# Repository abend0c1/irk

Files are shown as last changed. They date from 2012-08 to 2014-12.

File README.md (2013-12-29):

IRK! Infrared Remote USB Keyboard
=================================
Control your computer with an IR remote
---------------------------------------

IRK! is an open-hardware Infrared Remote Controlled USB keyboard, without keys, implemented using a PIC micro-controller and MikroC. It enables you to use your *learning* remote control to control any system that you can plug a USB keyboard into (Windows, Linux, Mac). Great for controlling a home theatre system such as MythTV, XBMC or Media Center. No drivers are required.

Note: Your IR remote *must* be able to *learn* infrared control signals. You *cannot* use a pre-programmed remote control with IRK!.

The original intention was to allow a user to control MythTV home theatre software using an infrared remote control. As it is seen by a PC as just another USB keyboard it can be used to control other PC functions as well.

What makes this unit different from the rest is that it can *teach* a learning remote control the IR code associated with a particular USB keystroke. As a result, there are *no* pre-programmed IR codes and IRK! does *not* have to support all the different types of infrared remotes on the market - it *teaches* the remote IRK!'s own infrared commands - which can be anything! Currently, IRK! uses Pulse Width Modulation (PWM) to encode/decode the infrared signals.

You can program -any- USB keyboard function (with or without Control, Alt, Shift and GUI modifiers) to a button on your infrared remote control and when you press that button IRK! will send the corresponding USB keystroke to the host computer.

You can program -any- USB Consumer Device control code too - for example, Play, Pause, Mute, Volume up, Volume down, and many others.

Features
--------
- Teaches your LEARNING remote control IR codes
- Lets you map IR codes to USB keystrokes - for example, Shift+Enter
- Sends the USB keystroke to your PC when you press a button on your infrared remote control
- Can send USB System Control codes (Power off, sleep, wake) to your PC
- Can can have one of 256 addresses - so you can have multiple IRK!'s
- Handles broadcasts - so multiple IRK!'s can respond to a single IR button
- Can remotely press the POWER and RESET buttons on your PC (if wired)
- Supports USB Consumer Device functions (e.g. Mute, Play, Pause, Stop, etc.)
- Has a programmable LCD backlight delay (and backlight ON/OFF commands)
- Requires NO drivers for Windows/Linux etc
- The Printed Circuit Board (PCB) comes in two flavours: 
  - Surface Mount Technology (SMT) and 
  - Through Hole Technology (THT)

Construction
------------
Go to the [Instructables](http://www.instructables.com/id/IRK-Infrared-Remote-Controlled-USB-Keyboard/) web site for detailed information on how to build your own unit.

Front Panel Buttons
-------------------

The front panel buttons comprise:

- UP - Press to increment the displayed function code. Press and hold to repeatedly increment the function code.
- DOWN - Press to decrement the displayed function code. Press and hold to repeatedly decrement the function code.
- OK - Press to accept an entry, or to cause the selected function to be executed.
- TEACH - Press to transmit a code representing the currently selected function to your IR remote control so that it can "learn" it.
- CTL - Press to toggle the keyboard "Ctrl" key. Press *and hold* to toggle the keyboard "GUI" key. The "GUI" key is a generic name for the "Windows" key on Microsoft keyboards, the "Apple" key on Apple keyboard, or the "Meta" or "Super" key on other keyboards. 
- ALT - Press to toggle the keyboard "Alt" key 
- SHIFT - Press to toggle the keyboard "Shift" key. Press *and hold* to select a different "usage page" (currently you can choose from Keyboard, Consumer Device, System Control, and local IRK! functions); then press UP/DOWN and OK to select the "usage page".

Front Panel Display 
-------------------

### Front Panel Display
The user is presented with an LCD 2 x 16 display that looks like:

<table style="border-collapse: collapse; width: 300px; text-align: left; background-color: #ccff00;">
  <tbody style="font-family: Courier New, courier, monospace; font-size: 20px; font-weight: bold; border: 10px solid #000000;">
    <tr><td style="padding-left:10px;width: 40px;">ux</td><td>line1</td></tr>
    <tr><td style="padding-left:10px;width: 40px;">yy</td><td>line2</td></tr>
  </tbody>
</table>

The codes, ux and yy, are hexadecimal values (that is, each digit can be from 0 to 9 and A to F).

-  u = The USB Usage Page index (i.e. used to assign meaning to the
      following x and yy codes). Press and hold the SHIFT button and
      then press the UP/DOWN buttons to cycle through the usage page
      indexes (0 to F and back to 0). At the moment, IRK! uses only
      the following usage page indexes:
    - 0 = Keyboard (A, B, C etc)
    - 1 = System Control (Power off, Sleep, Wake etc)
    - 2 = Consumer Devices (Mute, Vol+, Vol-, Play/Pause etc)
    - F = IRK! Local Functions (LCD backlight on/off etc)
- x = Either:
    - The key modifiers [Ctl, Alt, Shift, GUI] for Keyboard usage (see below), or else
    - The first nybble of xyy (the function to be performed) for all
          other usage pages.
- line1 = Text that describes the ux code
- yy = See below. Press and/or hold the UP and DOWN buttons to change
           the value of xyy.
- line2 = Text that describes the yy (or xyy) code.

The meanings id u, x and yy are as follows:

- When u = 0, xyy represents a Keyboard function:
    - 0x yy
         -    0 = Keyboard device
         -    x = Keyboard modifier (CTRL/ALT/SHIFT/GUI) flag bits (see below)
         -    yy = USB keyboard function code
    - 00 yy   Key yy pressed with no keyboard modifier keys
    - 01 yy   CTRL key pressed along with key yy
    - 02 yy   SHIFT key presed along with key yy
    - 04 yy   ALT key pressed along with key yy
    - 08 yy   GUI key pressed along with key yy
    
    Examples:
    - 00 05   b key pressed (05 is the code for "b")
    - 02 05   SHIFT+b key pressed (i.e. upper case B)
    - 06 05   ALT+SHIFT+b key pressed: 04(ALT) + 02(SHIFT) = 06(ALT+SHIFT)
    - 0C 05   GUI+SHIFT+b key pressed: 04(ALT) + 08(GUI)   = 0C(ALT+GUI)  

- When u = 1, xyy represents a System Control function:
    - 1x yy
         -    1 = System Control
         -    xyy = USB System Control function
    
    Examples:
    - 10 81   Power off
    - 10 82   Sleep
    - 10 83   Wake

- When u = 2, xyy represents a Consumer Device function:
    - 2x yy
         -   2 = Consumer Device
         -   xyy = USB Consumer Device function
     
    Examples:
    - 20 E2   Mute
    - 20 E9   Vol+
    - 20 EA   Vol-
    - 21 95   Internet Browser

- When u = F, xyy represents a local IRK! function (i.e. not USB):
    - Fx yy
         -   F = IRK! device
         -   xyy = Local IRK! device function
    - F0 00   Set Address ... the next LCD display will be:
        -    aa <-- Address
        -    00 Set Address
        -    You then press up/down to cycle the address (aa) then
             press OK to select it. The default address is AA.
    - F0 01   Power Switch
        - The two header pins marked PWR will become low impedance for about
          250 ms.  Note: this is not meant to switch large currents. The 4066
          quad analog switch can pass an absolute maximum of only +/- 25 mA.
    - F0 02   Reset Switch
        - The two header pins marked RST will become low impedance for about
          250 ms.
    - F0 03   Init USB
        - Causes the unit to re-register itself as a USB device. It is
          almost the equivalent of unplugging and replugging the device
          into a USB port.
    - F0 04   Back light off
        - Turns the LCD back light off
    - F0 05   Back light on
        - Turns the LCD back light off
    - F0 06   Set light delay  
        - Lets you set how many seconds you would like the LCD
          backlight to remain on after you have pressed a panel 
          button or issued a valid infrared command.
        - The next LCD display will be one of the following:
            -   xx <-- nnn secs (where nnn is xx in decimal)
            -   FF <-- ON       (keep back light always on)
            -   00 <-- OFF      (keep back light always off)
        -   You then press up/down to choose the delay value (xx) then
            press OK to select it.
    - F0 07   Debug on 
        - Displays debug information on the LCD when an IR code is received
    - F0 08   Debug off 
        - Returns the unit to Normal mode (displays no debug information on the LCD)
    - F0 09   Auxiliary Switch
        - The two header pins marked AUX will become low impedance for about
          250 ms.
    - F0 0A   Power Switch On
        - The two header pins marked PWR will become low impedance until a
          subsequent Power Switch Off command is received.
    - F0 0B   Reset Switch On
        - The two header pins marked RST will become low impedance until a
          subsequent Power Switch Off command is received.
    - F0 0C   Auxiliary Switch On
        - The two header pins marked AUX will become low impedance until a
          subsequent Power Switch Off command is received.
    - F0 0D   Power Switch Off
        - The two header pins marked PWR will become high impedance.
    - F0 0E   Reset Switch Off
        - The two header pins marked RST will become high impedance.
    - F0 0F   Auxiliary Switch Off
        - The two header pins marked AUX will become high impedance.

- Other values (u = 3 to F) are currently reserved for future use.
            
Examples
--------            
1. The user wants to program the Enter key on the OK button of a
   learning remote control. The steps to follow are:
    - Plug IRK! into a host USB port
    - The default usage mode is Keyboard, which is displayed as
    "00 Keyboard" in the first line of the LCD, so just
    press and hold the UP button until the second line of the LCD
    shows "28 Enter".
    - Switch your learning remote control into "Learn" mode and
    select the remote's button to be programmed.
    - Press IRK!'s TEACH button. This will send an IR code that
    means "Enter" to your learning remote.
    - Repeat until the learning remote has learned that IR code.
    - Press the programmed button on the learning remote control.
    - Verify that IRK! has received the IR code (it will flash
    its LED when it has recognised a valid IR code). Verify 
    that the "Enter" USB Keyboard function has been performed
    at the host.

2. The user wants to program the "Mute" Consumer Devices function
   on the "Mute" button of a learning remote control. The default
   usage mode of IRK! is "Keyboard", so you need to switch IRK! into
   "Consumer Dev" mode first:
    - Press and hold IRK!'s SHIFT button until the second line of
    the LCD shows "^^ Select Usage".
    - Press IRK!'s UP button until "20 Consumer Dev" is displayed in
    the first line of the LCD.
    - Press IRK!'s OK button to enter "Consumer Dev" usage mode.
    - Press and hold IRK!'s UP button until "E2 Mute" is displayed
    on the second line of the LCD. If you overshoot then press the
    DOWN button repeatedly until you reach "E2 Mute".
    - Press OK to verify that the Mute function is accepted by the
    host.
    - Put your learning remote control into "Learn" mode and choose
    one of the remote's buttons to be programmed as "Mute".
    - Position your learning remote's IR receiver to within 5 cm of
    IRK!'s IR transmitter LED.
    - Press IRK!'s TEACH button. This will send an IR code that 
    means "Mute" to your learning remote.
    - Keep pressing TEACH until the learning remote has learned that
    IR code.
    - Press the programmed button on the learning remote control.
    - Verify that IRK! has received the IR code (it will flash
    its LED when it has recognised a valid IR code). Verify 
    that the "Mute" USB consumer device function has been performed
    at the host.

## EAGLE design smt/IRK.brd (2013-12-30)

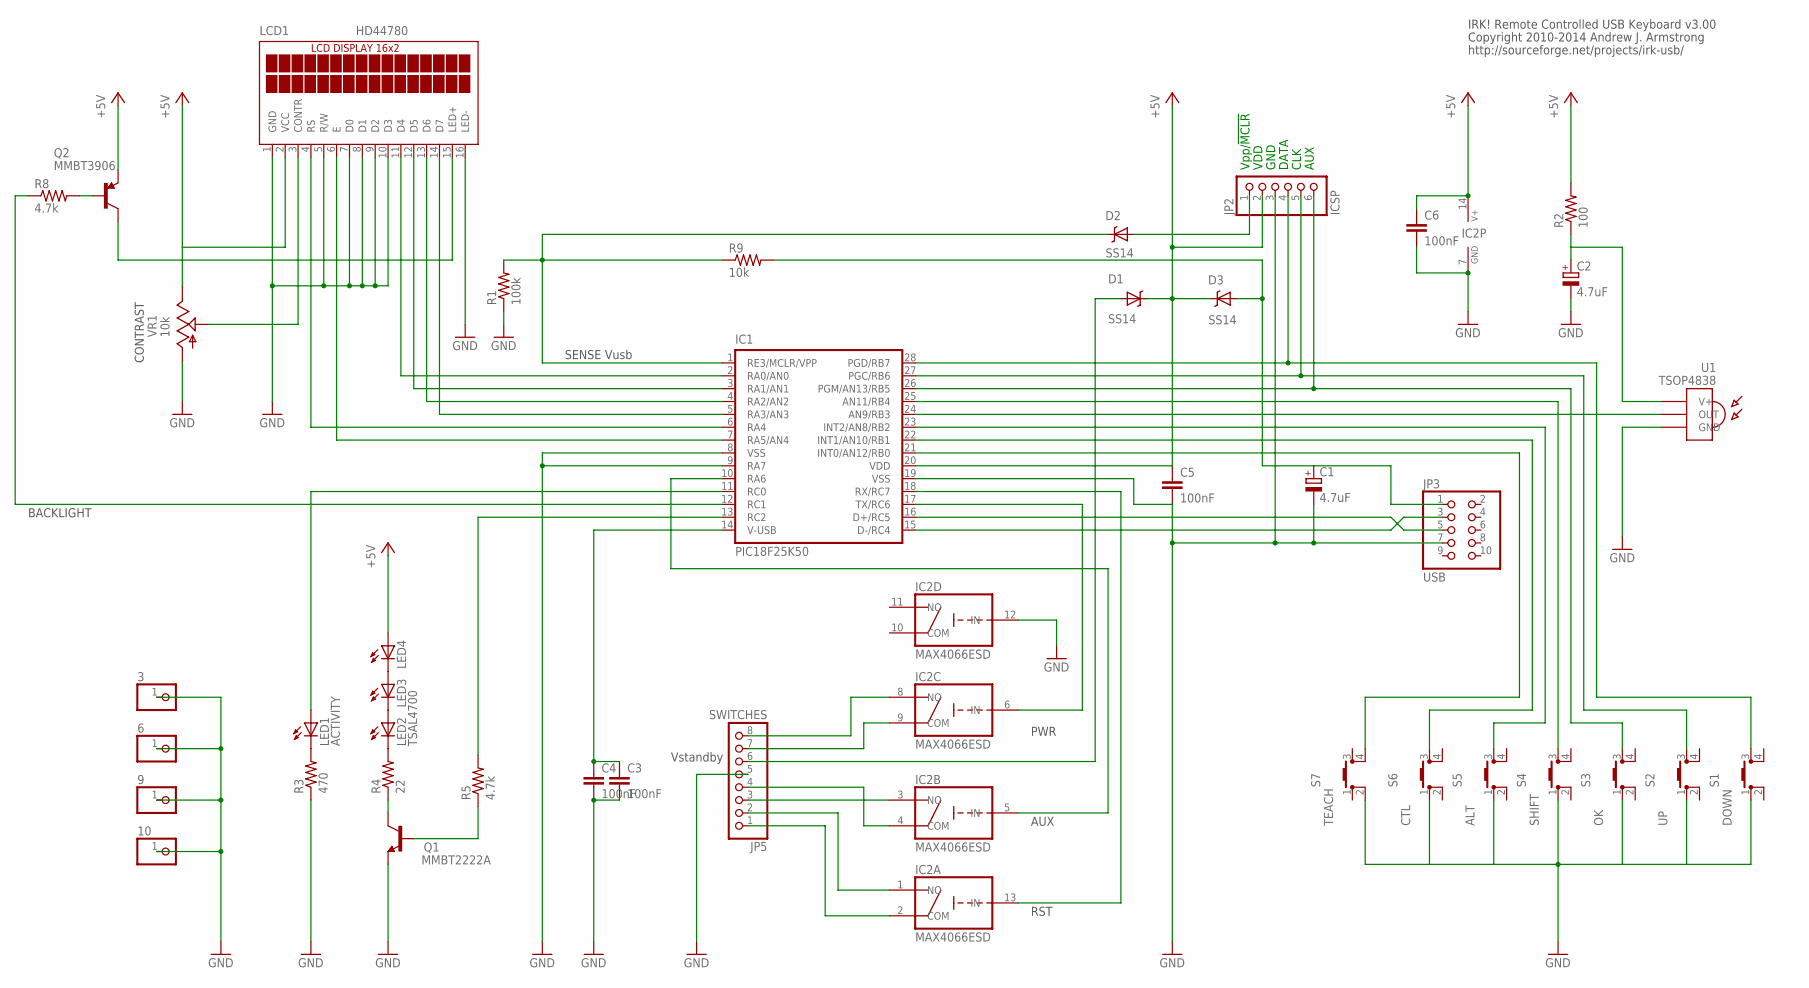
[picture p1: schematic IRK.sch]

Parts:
3, 6, 9, 10: 1X01
C1, C2: 4.7uF; SMC_A
C3, C4, C5, C6: 100nF; C0805
D1, D2, D3: SS14; SMA-DIODE
IC1: PIC18F25K50; SO28W
IC2: MAX4066ESD; SO14
JP2: ICSP; 1X06
JP3: USB; 2X05
JP5: SWITCHES; 1X08
LCD1: HD44780; LCD_16X2
LED1: ACTIVITY; LED5MM
LED2: TSAL4700; LED5MM
LED3, LED4: LED5MM
Q1: MMBT2222A; SOT23
Q2: MMBT3906; SOT23
R1: 100k; M1206
R2: 100; M1206
R3: 470; M1206
R4: 22; M1206
R5, R8: 4.7k; M1206
R9: 10k; M1206
S1: DOWN; PTH525-SM10
S2: UP; PTH525-SM10
S3: OK; PTH525-SM10
S4: SHIFT; PTH525-SM10
S5: ALT; PTH525-SM10
S6: CTL; PTH525-SM10
S7: TEACH; PTH525-SM10
U1: TSOP4838; TSOP18XX
VR1: 10k; 3303W

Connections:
+5V: C5.1, C6.1, D1.K, D3.K, IC1.20 (VDD), IC2.14 (V+), JP2.2, LCD1.2 (VCC), LED4.A, Q2.2 (E), R2.2, VR1.3 (E)
AUX: IC1.10 (RA6), IC2.5 (IN)
GND: 3.1, 6.1, 9.1, 10.1, C1.-, C2.-, C3.2, C4.2, C5.2, C6.2, IC1.8 (VSS), IC1.9 (RA7), IC1.19 (VSS), IC2.7 (GND), IC2.12 (IN), JP2.3, JP3.7, JP5.5, LCD1.1 (GND), LCD1.5 (R/W), LCD1.7 (D0), LCD1.8 (D1), LCD1.9 (D2), LCD1.10 (D3), LCD1.16 (LED-), Q1.2 (E), R1.1, R3.1, S1.1, S2.1, S3.1, S4.1, S5.1, S6.1, S7.2, U1.GND, VR1.1 (A)
unnamed: IC1.2 (RA0/AN0), LCD1.11 (D4)
unnamed: IC1.3 (RA1/AN1), LCD1.12 (D5)
unnamed: IC1.4 (RA2/AN2), LCD1.13 (D6)
unnamed: IC1.5 (RA3/AN3), LCD1.14 (D7)
unnamed: IC1.6 (RA4), LCD1.4 (RS)
unnamed: IC1.7 (RA5/AN4), LCD1.6 (E)
unnamed: LCD1.3 (CONTR), VR1.2 (S)
unnamed: D2.K, IC1.1 (RE3/MCLR/VPP), R1.2, R9.1
unnamed: IC1.24 (AN9/RB3), U1.OUT
unnamed: IC2.2 (COM), JP5.1
unnamed: IC1.28 (PGD/RB7), JP2.4, S1.3
unnamed: IC1.27 (PGC/RB6), JP2.5, S2.3
unnamed: IC1.26 (PGM/AN13/RB5), JP2.6, S3.3
unnamed: IC1.25 (AN11/RB4), S4.3
unnamed: IC1.23 (INT2/AN8/RB2), S5.3
unnamed: IC1.22 (INT1/AN10/RB1), S6.3
unnamed: IC1.21 (INT0/AN12/RB0), S7.4
unnamed: C3.1, C4.1, IC1.14 (V-USB)
unnamed: LED1.K (C), R3.2
unnamed: C1.+, D3.A, JP3.1, R9.2
unnamed: IC2.1 (NO), JP5.2
unnamed: IC1.16 (D+/RC5), JP3.5
unnamed: IC1.15 (D-/RC4), JP3.3
unnamed: LED2.K (C), R4.2
unnamed: LED2.A, LED3.K (C)
unnamed: LED3.A, LED4.K (C)
unnamed: IC1.13 (RC2), R5.2
unnamed: Q1.1 (B), R5.1
unnamed: Q1.3 (C), R4.1
unnamed: LCD1.15 (LED+), Q2.3 (C)
unnamed: IC2.4 (COM), JP5.4
unnamed: IC1.12 (RC1), R8.1
unnamed: IC2.3 (NO), JP5.3
unnamed: Q2.1 (B), R8.2
unnamed: IC2.9 (COM), JP5.7
unnamed: IC2.8 (NO), JP5.8
unnamed: D2.A, JP2.1
unnamed: IC1.11 (RC0), LED1.A
unnamed: C2.+, R2.1, U1.VCC (V+)
PWR: IC1.17 (TX/RC6), IC2.6 (IN)
RST: IC1.18 (RX/RC7), IC2.13 (IN)
VSB: D1.A, JP5.6

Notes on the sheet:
RST
PWR
CONTRAST
Copyright 2010-2014 Andrew J. Armstrong
http://sourceforge.net/projects/irk-usb/
IRK! Remote Controlled USB Keyboard v3.00
BACKLIGHT
SENSE Vusb
Vpp/!MCLR
VDD
GND
DATA
CLK
AUX
Vstandby

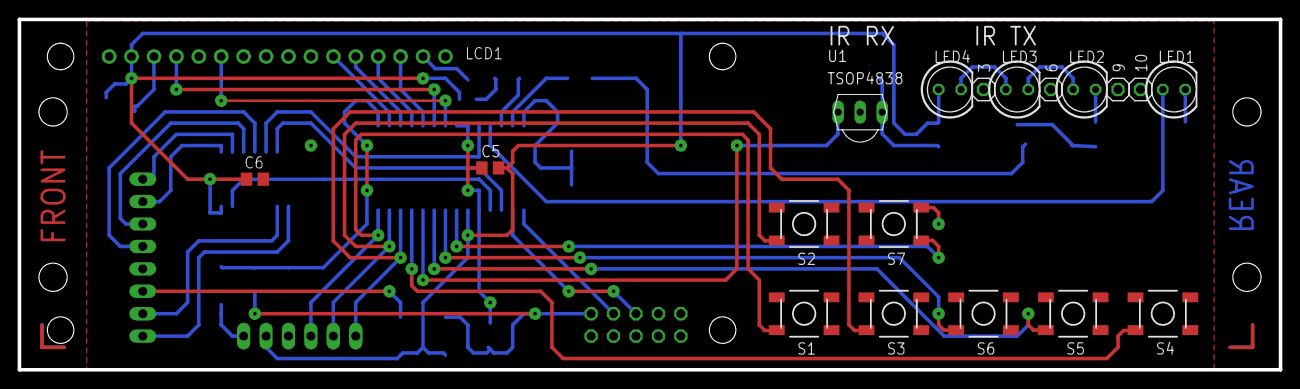
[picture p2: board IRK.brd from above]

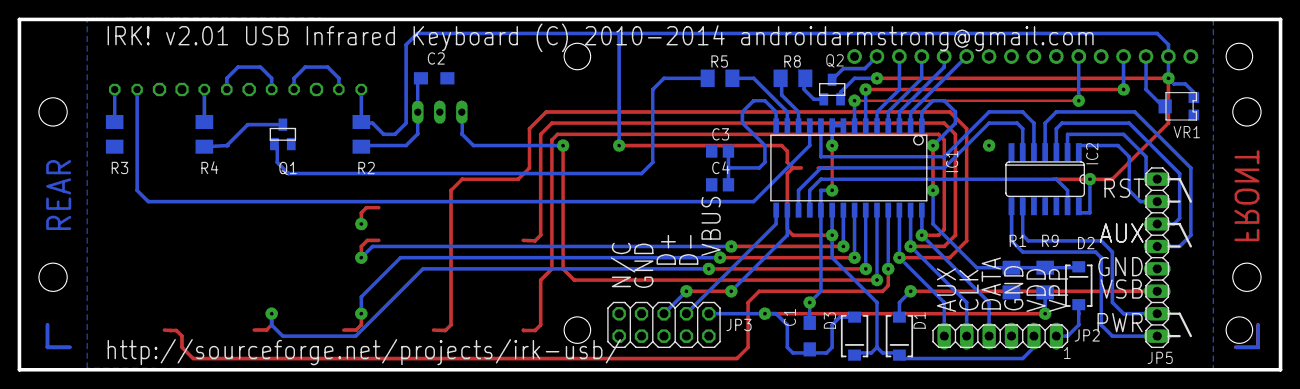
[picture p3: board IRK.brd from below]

Board: 2 copper layers, 142.9 x 39.7 mm, 41 parts (22 on the bottom side), 45 nets.

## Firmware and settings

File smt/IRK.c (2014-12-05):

/*
  IRK! Infrared Remote Controlled USB Keyboard $Rev:  $
  Copyright (C) 2010-2014 Andrew J. Armstrong

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
  You should have received a copy of the GNU General Public License
  along with this program; if not, write to the Free Software
  Foundation, Inc., 59 Temple Place, Suite 330, Boston, MA
  02111-1307  USA

  Author:
  Andrew J. Armstrong <androidarmstrong@gmail.com>
*/

/*
-------------------------------------------------------------------------------

NAME     - IRK! Infrared USB Keyboard

FUNCTION - This implements a USB keyboard that is controlled by a learning
           infrared remote control. Note: your IR remote MUST be able to LEARN
           infrared control signals. You CANNOT use a pre-programmed remote
           control with IRK!.

           The original intention was to allow a user to control MythTV home
           theatre software using an infrared remote control, but because it
           is seen by a PC as just another USB keyboard then it could be used
           to control other PC functions as well.

           What makes this unit different from the rest is that it can TEACH
           a learning remote control the IR code associated with a particular
           USB keystroke. As a result, there are NO pre-programmed IR codes and
           IRK! does not have to support all the different types of infrared
           remotes on the market - it TEACHES the remote IRK!'s own infrared
           commands - which can be anything! Currently, IRK! uses Pulse Width
           Modulation (PWM) to encode/decode the infrared signals.

FEATURES -
           IRK! teaches your LEARNING remote control IR codes
           IRK! lets you map IR codes to USB keystrokes (e.g. Shift+Enter)
           IRK! sends the USB keystroke to your PC when you press an IR button
           IRK! can send USB System Control codes (Power off, sleep, wake) to your PC
           IRK! devices can have one of 256 addresses (so you can have multiple IRK!'s)
           IRK! supports USB Consumer Device functions (e.g. Mute)
           IRK! has a programmable LCD backlight delay (or ON/OFF commands)
           IRK! needs no host drivers on Windows, Linux etc

PIN USAGE -                      PIC18F25K50
                            .------------------.
            (Sense USB) --> | RE3  1    28 RB7 | <-- (DOWN button)
            (LCD D4)    <-- | RA0  2    27 RB6 | <-- (UP button)
            (LCD D5)    <-- | RA1  3    26 RB5 | <-- (OK button)
            (LCD D6)    <-- | RA2  4    25 RB4 | <-- (SHIFT button)
            (LCD D7)    <-- | RA3  5    24 RB3 | <-- (IR receiver)
            (LCD RS)    <-- | RA4  6    23 RB2 | <-- (ALT button)
            (LCD EN)    <-- | RA5  7    22 RB1 | <-- (CTL/GUI button)
            (Ground)    --- | VSS  8    21 RB0 | <-- (TEACH button)
            (n/c)       --- | RA7  9    20 VDD | --- (+5V)
            (AUX switch)<-- | RA6  10   19 VSS | --- (Ground)
            (LED)       <-- | RC0  11   18 RC7 | --> (RST switch)
            (Backlight) <-- | RC1  12   17 RC6 | --> (PWR switch)
            (IR LED)    <-- | RC2  13   16 RC5 | <-> (USB D+)
            (220nF)     --- | VUSB 14   15 RC4 | <-> (USB D-)
                            '------------------'

CONFIG    - The PIC18F25K50 configuration fuses should be set as follows (items
            marked with '*' are essential for IRK! to operate correctly):

            CONFIG1L 2B 00101011
                          1      = *LS48MHZ: System clock is expected at 48 MHz, FS/LS USB clock divide-by is set to 8
                           01    = *CPUDIV: CPU system clock (48 MHz) divided by 2 (= 24 MHZ)
                             0   =  Unimplemented
                              x  =  CFGPLLEN: (ignored, set dynamically)
                               x =  PLLSEL: (ignored, set dynamically)
            CONFIG1H 28 00101000
                        0        =  IESO: Oscillator Switchover mode disabled
                         0       =  FCMEN: Fail-Safe Clock Monitor disabled
                          1      = *PCLKEN: Primary Clock is always enabled
                           0     =  Unimplemented
                            1000 = *FOSC: Internal oscillator block
            CONFIG2L 5F 01011111
                        0        =  Unimplemented
                         1       =  LPBOR: Low-Power Brown-out Reset disabled
                          0      =  Unimplemented
                           11    =  BORV: VBOR set to 1.9V nominal
                             11  =  BOREN: Brown-out Reset enabled in hardware only (SBOREN is disabled)
                               1 =  PWRTEN: Power-up Timer disabled
            CONFIG2H 3C 00111100
                        00       =  Unimplemented
                          1111   =  WDTPS: Watchdog Timer Postscale Select = 1:32768
                              00 =  WDTEN: Watchdog Timer disabled in hardware, SWDTEN bit disabled
            CONFIG3L 00 00000000
                        00000000 =  Unimplemented
            CONFIG3H 53 01010000
                        0        = *MCLRE: RE3 input pin enabled; MCLR disabled
                         1       =  SDOMX: SDO is on RB3
                          0      =  Unimplemented
                           1     =  T3CMX: T3CKI is on RC0
                            00   =  Unimplemented
                              0  =  PDADEN: ANSELB<5:0> resets to 0, PORTB<4:0> pins are configured as digital I/O on Reset
                               0 = *CCP2MX: CCP2 input/output is multiplexed with RB3
            CONFIG4L 81 10000001 =  Default
            CONFIG5L 0F 00001111 =  Default
            CONFIG5H C0 11000000 =  Default
            CONFIG6L 0F 00001111 =  Default

OPERATION - The user is presented with an LCD 2 x 16 display that looks like:

            .----------------.
            |ux line1........|
            |yy line2........|
            '----------------'

            u = The USB Usage Page index (i.e. used to assign meaning to the
                following x and yy codes). Press and hold the SHIFT button and
                then press the UP/DOWN buttons to cycle through the usage page
                indexes (0 to F and back to 0). At the moment, IRK! uses only
                the following usage page indexes:
                0 = Keyboard (A, B, C etc)
                1 = System Control (Power off, Sleep, Wake etc)
                2 = Consumer Devices (Mute, Vol+, Vol-, Play/Pause etc)
                F = IRK! Local Functions (LCD backlight on/off etc)
            x = The key modifiers (Ctl, Alt, Shift) for Keyboard usage, else
                the top nybble of xyy (the function to be performed) for all
                other usages.
            line1 = Text that describes the ux code
            yy = See below. Press and/or hold the UP and DOWN buttons to change
                 the value of xyy.
            line2 = Text that describes the yy (or xyy) code.


            The meanings id u, x and yy are as follows:

            For the Keyboard usage:
            ux yy
            0      Keyboard
                     x = Keyboard modifier (CTRL/ALT/SHIFT) flag bits
                     yy = USB keyboard function code
            00 yy   Key yy pressed with no keyboard modifier keys
            01 yy   CTRL key pressed along with key yy
            02 yy   SHIFT key presed along with key yy
            04 yy   ALT key pressed along with key yy
            08 yy   GUI key pressed along with key yy
            Examples:
            00 05   b key pressed
            02 05   SHIFT+b key pressed (i.e. upper case B)
            06 05   ALT+SHIFT+b key pressed



            For the System Control usage:
            ux yy
            1      System Control
                     xyy = USB System Control function
            Examples:
            10 81   Power off
            10 82   Sleep
            10 83   Wake



            2      Consumer Devices
                   xyy = USB Consumer Device function
            Examples:
            20 E2   Mute
            20 E9   Vol+
            20 EA   Vol-
            21 95   Internet Browser



            The following are spare usage indexes:
            ux yy
            3      --reserved for future use--
            4      --reserved for future use--
            5      --reserved for future use--
            6      --reserved for future use--
            7      --reserved for future use--
            8      --reserved for future use--
            9      --reserved for future use--
            A      --reserved for future use--
            B      --reserved for future use--
            C      --reserved for future use--
            D      --reserved for future use--
            E      --reserved for future use--



            For the Local IRK! Functions usage:
            ux yy
            F      Local IRK! functions (i.e. not USB)
            F0 00  Set Address ... the next LCD display will be:
                   - aa <-- Address
                   - 00 Set Address
                   - You then press up/down to cycle the address (aa) then
                     press OK to select it. The default address is AA.
            F0 01  Power Switch
                   - The two header pins marked PWR will become low impedance for about
                     250 ms.  Note: this is not meant to switch large currents. The 4066
                     quad analog switch can pass an absolute maximum of only +/- 25 mA.
            F0 02  Reset Switch
                   - The two header pins marked RST will become low impedance for about
                     250 ms.
            F0 03  Init USB
                   - Causes the unit to re-register itself as a USB device. It is
                     almost the equivalent of unplugging and replugging the device
                     into a USB port.
            F0 04  Back light off
                   - Turns the LCD back light off
            F0 05  Back light on
                   - Turns the LCD back light off
            F0 06  Set light delay  
                   - Lets you set how many seconds you would like the LCD
                     backlight to remain on after you have pressed a panel 
                     button or issued a valid infrared command.
                   - The next LCD display will be one of the following:
                     - xx <-- nnn secs (where nnn is xx in decimal)
                     - FF <-- ON       (keep back light always on)
                     - 00 <-- OFF      (keep back light always off)
                   - You then press up/down to choose the delay value (xx) then
                     press OK to select it.
            F0 07  Debug on 
                   - Displays debug information on the LCD when an IR code is received
            F0 08  Debug off 
                   - Returns the unit to Normal mode (displays no debug information on the LCD)
            F0 09  Auxiliary Switch (4066 analog switch number 3)
                   - The two header pins marked AUX will become low impedance for about
                     250 ms.
            F0 0A  Power Switch On
                   - The two header pins marked PWR will become low impedance until a
                     subsequent Power Switch Off command is received.
            F0 0B  Reset Switch On
                   - The two header pins marked RST will become low impedance until a
                     subsequent Power Switch Off command is received.
            F0 0C  Auxiliary Switch On
                   - The two header pins marked AUX will become low impedance until a
                     subsequent Power Switch Off command is received.
            F0 0D  Power Switch Off
                   - The two header pins marked PWR will become high impedance.
            F0 0E  Reset Switch Off
                   - The two header pins marked RST will become high impedance.
            F0 0F  Auxiliary Switch Off
                   - The two header pins marked AUX will become high impedance.


FORMATS -  1. The IR transmission format sent to, and received from, your
           Learning Remote control is:

            aa aa' ux ux' yy yy'

            That is:
            aa  = The address of this IRK! device
            aa' = The address of this IRK! device inverted
            ux  = The ux byte as described above
            ux' = The ux byte inverted
            yy  = The yy byte as decribed above
            yy' = The yy byte inverted

            The same data format is received from your Learning Remote when
            you press one of the IRK! functions recorded by it.

           2. The USB transmission format sent to your PC varies depending on
           the USB usage as follows:

            Usage                      USB Report format
            0 (Keyboard)               'K' 0x 00 yy
            1 (System Control)         'S' yy
            2 (Consumer Device)        'C' 0x yy
            3                          --reserved--
            4                          --reserved--
            5                          --reserved--
            6                          --reserved--
            7                          --reserved--
            8                          --reserved--
            9                          --reserved--
            A                          --reserved--
            B                          --reserved--
            C                          --reserved--
            D                          --reserved--
            E                          --reserved--
            F (Local IRK! Device)      No USB report sent

            The reason for translating the Usage nybble to an ASCII character
            for the Report ID (e.g. 0 becomes 'K') is to make it easier to
            interpret USB traces captured on the host. That is the only reason.
            You can just as easily configure the USB Report Descriptors to use
            0x00 for Keyboard, 0x01 for System Control etc.
            The USB Report Id is used by the host HID driver to distinguish
            between the various reports sent by IRK!.
            See USBdsc.c to see how the Report Id is defined.
            See the "Device Class Definition for Human Interface Devices (HID)"
            documentation, specifically "Section 5.6 Reports" at:
            http://www.usb.org/developers/devclass_docs/HID1_11.pdf
            ...for more information on Report Id.

EXAMPLE  - 1. The user wants to program the Enter key on the OK button of a
              learning remote control. The steps to follow are:
              a. Plug IRK! into a host USB port
              b. The default usage mode is Keyboard, which is displayed as
                 "00 Keyboard" in the first line of the LCD, so just
                 press and hold the UP button until the second line of the LCD
                 shows "28 Enter".
              c. Switch your learning remote control into "Learn" mode and
                 select the remote's button to be programmed.
              d. Press IRK!'s TEACH button. This will send an IR code that
                 means "Enter" to your learning remote.
              e. Repeat until the learning remote has learned that IR code.
              f. Press the programmed button on the learning remote control.
              g. Verify that IRK! has received the IR code (it will flash
                 its LED when it has recognised a valid IR code). Verify 
                 that the "Enter" USB Keyboard function has been performed
                 at the host.

           2. The user wants to program the "Mute" Consumer Devices function
              on the "Mute" button of a learning remote control. The default
              usage mode of IRK! is "Keyboard", so you need to switch IRK! into
              "Consumer Dev" mode first:
              a. Press and hold IRK!'s SHIFT button until the second line of
                 the LCD shows "^^ Select Usage".
              b. Press IRK!'s UP button until "20 Consumer Dev" is displayed in
                 the first line of the LCD.
              c. Press IRK!'s OK button to enter "Consumer Dev" usage mode.
              d. Press and hold IRK!'s UP button until "E2 Mute" is displayed
                 on the second line of the LCD. If you overshoot then press the
                 DOWN button repeatedly until you reach "E2 Mute".
              e. Press OK to verify that the Mute function is accepted by the
                 host.
              f. Put your learning remote control into "Learn" mode and choose
                 one of the remote's buttons to be programmed as "Mute".
              g. Position your learning remote's IR receiver to within 5 cm of
                 IRK!'s IR transmitter LED.
              h. Press IRK!'s TEACH button. This will send an IR code that 
                 means "Mute" to your learning remote.
              i. Keep pressing TEACH until the learning remote has learned that
                 IR code.
              j. Press the programmed button on the learning remote control.
              k. Verify that IRK! has received the IR code (it will flash
                 its LED when it has recognised a valid IR code). Verify 
                 that the "Mute" USB consumer device function has been performed
                 at the host.
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
void main()
{
  Prolog();

  while (FOREVER)
  {
    if (bInfraredInterruptPending)
    {
      processInfraredInterrupt();
      bInfraredInterruptPending = 0;
    }
    if (ACTIVITY_LED)
    {
      if (--nActivityLEDDelay == 0)
      {
        ACTIVITY_LED = OFF;
      }
    }
    if (((PORTB & 0b11110111) ^ 0b11110111))     // If any button is pressed (low)
    {
      enableBacklight();          // Conditionally turn on LCD backlight
      Delay_ms(25);               // Debounce delay
      nKeyRepeatDelay = KEY_REPEAT_DELAY_IN_TICKS;  // Number of Timer3 interrupts before starting key repeat
      TMR3H = 0;                  // Prime the Timer3 high byte
      TMR3L = 0;                  // Now clear the Timer3 counter
      TMR3ON_bit = ON;            // Turn on the key repeat timer
      if (!bSettingUsage && !bSettingDeviceAddress && !bSettingBacklightDelay)
      {
        if (TEACH_BUTTON_PRESSED)   // Transmit the current key via infrared
        {
          transmitInfraredCommand();
          while (TEACH_BUTTON_PRESSED); // Wait for button to be released
        }
        if (CTL_BUTTON_PRESSED) handleCtlButton();
        if (ALT_BUTTON_PRESSED)         // Toggle the ALT key modifier
        {
          usbCommand.s.ux.bits.LeftAlt ^= 1;
          while (ALT_BUTTON_PRESSED);   // Wait for button to be released
        }
        if (SHIFT_BUTTON_PRESSED) handleShiftButton();
      }
      if (OK_BUTTON_PRESSED)    handleOKButton();
      if (UP_BUTTON_PRESSED)    adjustBy(+1, &isUpButtonPressed);
      if (DOWN_BUTTON_PRESSED)  adjustBy(-1, &isDownButtonPressed);
      TMR3ON_bit = OFF;                 // Turn off the key repeat timer
      bKeyRepeatPending = FALSE;
      updateLCD();                      // Show final key state
    }
    if (bLastUSBPower ^ USB_POWER_GOOD) // If USB power state has changed
    {
      if (USB_POWER_GOOD)               // If USB is now powered
        enableUSB();                    // Then enable USB interface
      else                              // Else USB is now unpowered
        disableUSB();                   // So disable USB interface
      bLastUSBPower = USB_POWER_GOOD;   // Remember the current USB power state
    }
  }
}

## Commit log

2012-08-14 Initial git commit - version 2.04
    [IRK.brd, IRK.cfg, IRK.sch]
2012-10-09 Fixed the pulse width check introduced in 2.04
    [IRK.c]
2012-10-20 Increased IR pulse width error margin and added debug mode
    [IRK.c]
2012-10-25 Added extra Consumer Device function descriptions
2012-12-12 Fixed bug when holding SHIFT during menu navigation
    [IRK.c]
2012-12-17 Updated pin usage diagram
2013-04-14 Recompile for MikroC 6.0
    [IRK.cfg]
2013-11-10 Added a new SMD double-sided board and schematic
    [IRK.brd, IRK.cfg, IRK.sch]
2013-11-16 Reworked SMD board layout
    [IRK.brd, IRK.sch]
2013-12-05 Added .gitattributes text=auto
    [IRK.cfg]
2013-12-05 Reworked project structure to accommodate SMD and THT versions.
    The orginal Through Hole Technology (THT) version is now stored
    in the tht/ directory and the new Surface Mount Technology (SMT)
    version is stored in the smt/ directory.
    [IRK.brd, IRK.cfg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]
2013-12-05 Cleaned up IRK.lbr (Eagle CAD device library)
    Also, added a footprint for a very cheap micro-tactile switch
    from Leye Electronics (China) - available on eBay. If you want
    to use it you will have to redesign the PCB slightly as it is
    a 6mm x 6mm SMT switch - larger than the C&K switch in the SMT
    version.
2013-12-05 Changed symbol for push button switches
    [IRK.sch]
2013-12-07 Added IRK Function Codes spreadsheet
    [IRK Function Codes.ods]
2013-12-07 Added Auxiliary switch logic
2013-12-10 Made cosmetic changes.
    1. Used the HID Report Descriptor Decoder (http://sourceforge.net/projects/hidrdd/)
    to document the report descriptor meaning.
    2. Changed the trimpot in IRK.lbr so that it has a tRestrict under it (this
    prevents copper traces being routed under the metal part of the trimpot).
    3. Improved the routing of the track for the 100nF capacitor under the PIC18F25K50
    chip.
    4. For the LCD library initialisation, used LAT registers instead of PORT registers
    (this probably doesn't make any difference to the operation).
    [IRK.brd, IRK.sch]
2013-12-10 Updated the CAM job to print component values on the top and bottom silk.
    [IRK Function Codes.ods]
2013-12-10 Updated the TSOP4838 IR receiver footprint to have the Name and Value on the tNames and tValues layers respectively. Was on tPlace in error.
2013-12-11 Replaced old 2550 device with P18F25K50 in IRK.lbr
    [IRK.brd, IRK.sch]
2013-12-11 Ran the smt/IRK.cam job to re-create the Gerber files
    These files (*.g*) can be sent to a PCB manufacturer. This time the
    component values will be printed on the silk layers. The batch I got
    back from Itead only had the component names (my bad).
    [IRK.gbl, IRK.gbo, IRK.gbs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]
2013-12-11 Added a script to zip up the gerber files. You specify the version to suffix the zip file name
2013-12-16 Spaced the holes for the IR TX and Activity LEDs at 0.1 inch intervals.
    Now (if you want) you can solder a 12x1 pin socket header and plug
    your IR TX and Activity LEDs into it rather than soldering them
    directly to the board. Long term reliability might be an issue
    as the leads oxidise though. The interspersed pin sockets appear on
    the schematic as grounded 1x1 header pins.
    The IR RX LED has remained slightly offset from the others, because it
    needs to be bent 90° so that it is perpendicular to the board.
    The board version is now 2.01 as a result of these minor layout changes
    and the Gerber files have been regenerated.
    [IRK.brd, IRK.sch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]
2013-12-21 Reworked to run at 48 MHz (instead of 24 MHz).
    - Fixed description of what the front panel buttons do in README.md
    - Changed some configuration fuses (CONFIGxx) for PIC18F25K50
    - Reworked the timer value calculations so that the MCU clock frequency
    can be reverted to 24 MHz more easily.
    - Minor changes to the Eagle PCB layout, library and schematic.
    Note: Infrared capture is still not working at the moment, but things
    that are working are:
    1. Front panel key navigation
    2. Press-and-hold key repeats
    3. Backlight timeout
    4. Teaching function (i.e. IR transmission is ok)
    5. IR reception is OK - it's just the interpretation of the command
    that is not being done at the moment.
    [IRK.brd, IRK.cfg, IRK.sch]
2013-12-28 Tidied up the source code a bit.
    [IRK.cfg]
2013-12-28 Tidied up the source code a bit.
    - Infrared capture works (it worked all along, it's just that I
    forgot to set the IRK device address to AA - the deafault is FF).
    [IRK.cfg]
2013-12-29 Added extra local IRK! functions to turn on and off the 4066 analog switches.
    The existing local functions merely asserted the selected analog
    switch (PWR, RST and AUX) for 250 ms. The new functions allow you
    to assert each analog switch until they are released by a
    subsequent OFF command.
2013-12-29 Renumbered the analog switch local IRK! function codes
2013-12-30 Updated the LCD package to have 3 mm mounting holes.
    The original ones were 2.5 mm but didn't match reality.
    So I had to drill out the mounting holes to 3 mm (or else
    find 2.5 mm bolts which are quite hard to find). M3 bolts
    are much more commonly available. Had to reroute one of the
    PCB traces to avoid a hole as a result.
    [IRK.brd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]
2014-08-31 Corrected documentation in USBdsc.c regarding EP_IN_INTERVAL. Added FPC connector to Eagle smt part library.
2014-12-05 Used Hi() and Lo() functions. Introduced ASSIGN macro to assign names to each LCD pin.

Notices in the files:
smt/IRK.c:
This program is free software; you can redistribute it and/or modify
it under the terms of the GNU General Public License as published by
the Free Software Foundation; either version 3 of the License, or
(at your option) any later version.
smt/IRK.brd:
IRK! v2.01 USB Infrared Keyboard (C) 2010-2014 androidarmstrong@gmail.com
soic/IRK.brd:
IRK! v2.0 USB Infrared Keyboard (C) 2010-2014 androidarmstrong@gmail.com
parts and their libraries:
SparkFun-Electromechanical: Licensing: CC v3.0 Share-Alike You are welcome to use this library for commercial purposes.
